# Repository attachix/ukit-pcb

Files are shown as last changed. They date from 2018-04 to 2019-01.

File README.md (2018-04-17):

## About
This repository contains the files needed to view, modify and manufacture the Printed Circuit Boards(PCB) for the [U:Kit sensor kit](https://github.com/attachix/ukit) project.

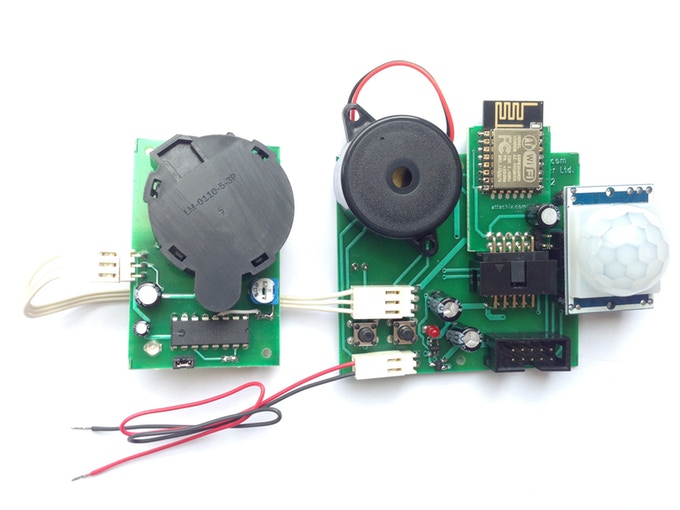
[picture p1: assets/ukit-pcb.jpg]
UKit PCBs
.

## PCBs
U:Kit consists currently of 3 PCBS
* [esp-board/](esp-board/) - ESP8266 PCB.
* [base-board/](base-board/) - the main board in the kit
* [smoke-board/](smoke-board) - the board that operates with the smoke sensor

## Hardware Overview
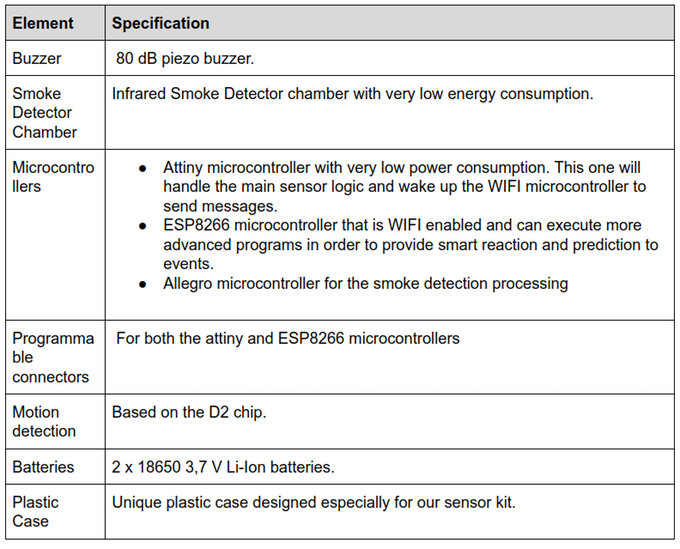
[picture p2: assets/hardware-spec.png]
Technical specification
.

## Required Software
For viewing and modifying the PCBs you will need [KiCad](http://kicad-pcb.org/) version 4.0.5 or newer.
In Ubuntu 16.04 you can install it by typing `sudo apt install kicad`.

### Optional Software
If you want to be able to see better the differences between versions you will need
* gerbv - for differences in Gerber files
* [ImageMagick](https://www.imagemagick.org) - for differences in image files
* diffpdf - for differences in PDF files
* eeplot - for differences in Schema files.

## Copyright
Copyright (c) 2016-2018, Slavey Karadzhov <slav@attachix.com>. All rights reserved.

## Authors
* Cviatko Delchev <cviatko@attachix.com> - Our hard-core hardware guru
* Slavey Karadzhov <slav@attachix.com>
* .. Contributors - See https://github.com/attachix/ukit-pcb/graphs/contributors

## License
All files in this repository are licensed under Creative Commons Non-Commercial-Share Alike 3.0 License . See the [LICENSE](LICENSE) file details. Basically it means that

### You are free to
* Share — copy and redistribute the material in any medium or format
* Adapt — remix, transform, and build upon the material

The licensor cannot revoke these freedoms as long as you follow the license terms.

### Under the following terms:
* Attribution — You must give appropriate credit, provide a link to the license, and indicate if changes were made. You may do so in any reasonable manner, but not in any way that suggests the licensor endorses you or your use.

* NonCommercial — You may not use the material for commercial purposes.

No additional restrictions — You may not apply legal terms or technological measures that legally restrict others from doing anything the license permits.

Credit can be attributed through a link to the creator website: https://attachix.com

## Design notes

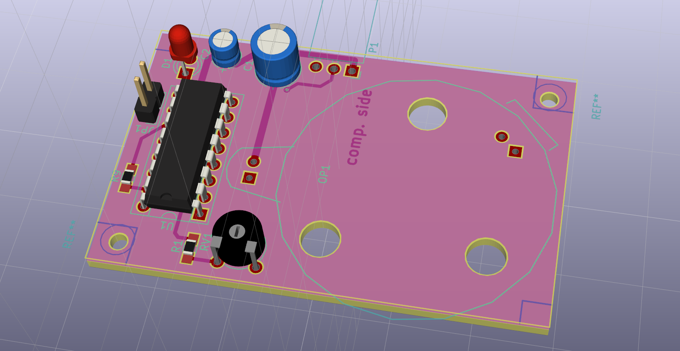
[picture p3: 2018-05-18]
smoke-board/model/CC_SM_mod_01.png

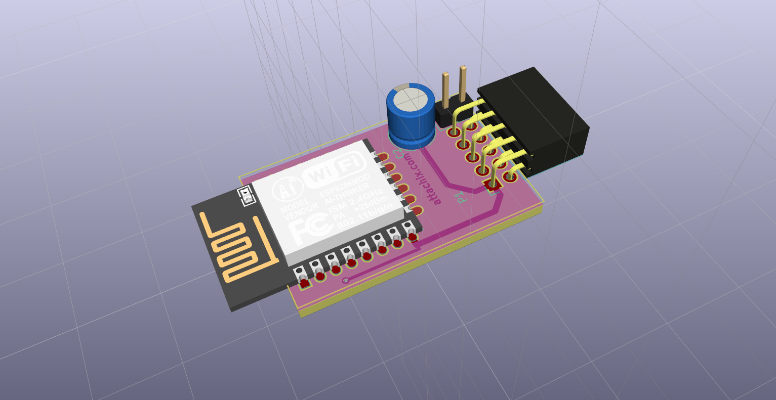
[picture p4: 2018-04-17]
esp-board/model/CC_ESP_mod_02.png

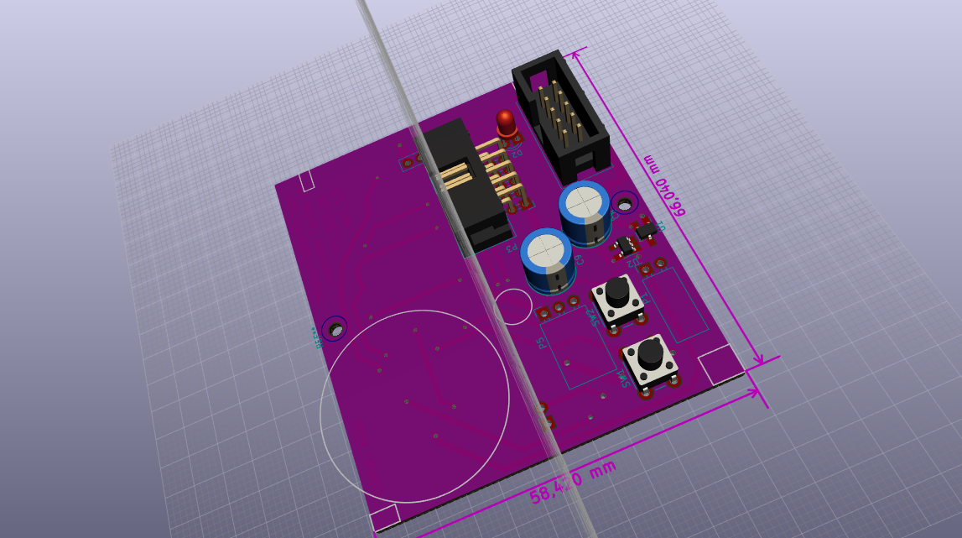
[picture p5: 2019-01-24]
base-board/model/CC_SM_mod_01.png

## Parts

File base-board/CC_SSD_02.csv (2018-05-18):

Reference | Value | Footprint | Datasheet | MF | MP | Specification | Quantity
IC1 | ATTINY1634-SU | CC_Footprint:SOIC-20W_7.5x12.8mm_Pitch1.27mm |  | Atmel | ATTINY1634-SU | https://www.verical.com/pd/atmel-microcontroller-ATTINY1634-SU-729132
P2 | BH10S | CC_Footprint:IDC_Header_Straight_10pins
P3 | BH10R | CC_Footprint:BH10R
P5 | WF3R | CC_Footprint:WF3R
P4 | PN1x3 | CC_Footprint:PN1x3
P6 | WF2R | CC_Footprint:WF2R |  | HITPOINT | PT-3110PQ | https://store.comet.bg/download-file.php?id=1015
P1 | WF2R | CC_Footprint:WF2R
U1 | MCP1701AT-3302I/CB | CC_Footprint:SOT-23_Handsoldering | MCP1701AT Series 250 mA 3.3 V LDO Positive Voltage Regulator - SOT-23 | Good | SOT-23 Microchip | Microchip | 0.65 USD | MCP1701AT-3302I/CB
U2 | MCP1802T-3302I/OT | CC_Footprint:SOT-23-5_HandSoldering | MCP1802T-3302I/OT
Q2 | DTC144TKA | CC_Footprint:SOT-23_Handsoldering
Q1 | DTC144TKA | CC_Footprint:SOT-23_Handsoldering
D2 | L-934LSRD | CC_Footprint:LED_D3.0mm
D1 | 1N5819 | CC_Footprint:D_SMA_Handsoldering
C8 | 220uF/10V | CC_Footprint:CP_Radial_D8.0mm_P2.50mm
C9 | 470uF/10V | CC_Footprint:CP_Radial_D8.0mm_P2.50mm
C4,C1,C3,C5 | 1uF | CC_Footprint:C_0805_HandSoldering
C6,C7,C11,C10,C2 | 100n | CC_Footprint:C_0805_HandSoldering
R1 | 1.8M | CC_Footprint:R_0805_HandSoldering
R2 | 200K | CC_Footprint:R_0805_HandSoldering
R11, R12 | 100k | CC_Footprint:R_0805_HandSoldering
R9, R10 | 0 | CC_Footprint:R_0805_HandSoldering
R8 | 10k | CC_Footprint:R_0805_HandSoldering
R14 | 330 | CC_Footprint:R_0805_HandSoldering
R5, R4, R3, R7, R6, R13 | 220 | CC_Footprint:R_0805_HandSoldering
SW2 | TS-06E | CC_Footprint:SW_PUSH_6mm
SW1 | TS-06E | CC_Footprint:SW_PUSH_6mm

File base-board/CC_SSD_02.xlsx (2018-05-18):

 |  |  |  |  |  |  | Board Qty: | 1
 |  |  |  |  |  |  | Total Cost: | $3.15 |  |  |  | $0.00 |  |  |  |  |  | $5.97 |  |  |  |  |  | $3.70 |  |  |  |  |  | $4.70 |  |  |  |  |  | $3.78
 |  |  |  |  |  |  | Unit Cost: | $3.15
Global Part Info |  |  |  |  |  |  |  |  | Digi-Key |  |  |  |  |  | Farnell |  |  |  |  |  | Mouser |  |  |  |  |  | Newark |  |  |  |  |  | Rs Components
Refs | Value | Desc | Footprint | Manf | Manf# | Qty | Unit$ | Ext$ | Avail | Purch | Unit$ | Ext$ | Cat# | Doc | Avail | Purch | Unit$ | Ext$ | Cat# | Doc | Avail | Purch | Unit$ | Ext$ | Cat# | Doc | Avail | Purch | Unit$ | Ext$ | Cat# | Doc | Avail | Purch | Unit$ | Ext$ | Cat# | Doc
C1,C3-C5 | 1uF |  | CC_Footprint:C_0805_HandSoldering |  |  | 4 | $0.00 | $0.00
P4 | PN1x3 |  | CC_Footprint:PN1x3 |  |  | 1 | $0.00 | $0.00
D2 | L-934LSRD |  | CC_Footprint:LED_D3.0mm |  | L-934LSRD | 1 | $0.11 | $0.11 |  |  |  |  |  |  | 4074 |  | $1.80 | $1.80 | 1142514 | Link (http://it.farnell.com/webapp/wcs/stores/servlet/Search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) |  |  |  |  | Not Assigned | Link (http://www.mouser.com/Search/../ProductDetail/Kingbright/L-934LSRD/) | 4074 |  | $0.11 | $0.11 | 26M0076 | Link (http://www.newark.com/webapp/wcs/stores/servlet/Search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)
C8 | 220uF/10V |  | CC_Footprint:CP_Radial_D8.0mm_P2.50mm |  |  | 1 | $0.00 | $0.00
R11,R12 | 100k |  | CC_Footprint:R_0805_HandSoldering |  |  | 2 | $0.00 | $0.00
R14 | 330 |  | CC_Footprint:R_0805_HandSoldering |  |  | 1 | $0.00 | $0.00
Q2 | DTC144TKA |  | CC_Footprint:SOT-23_Handsoldering | ROHM | DTC144T | 1 | $0.06 | $0.06 |  |  |  |  |  |  |  |  |  |  |  |  | 5235 |  | $0.34 | $0.34 | 755-DTC144TETL | Link (http://www.mouser.com/Search/../ProductDetail/ROHM-Semiconductor/DTC144TETL/) | 20 |  | $0.06 | $0.06 | 89Y7187 | Link (http://www.newark.com/webapp/wcs/stores/servlet/Search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) | 315 |  | $0.08 | $0.08 | 246-1738 | Link (http://it.rs-online.com/web/c/?searchTerm=DTC144T%20ROHM)
Q1 | DTC144TKA |  | CC_Footprint:SOT-23_Handsoldering | ROHM | DTC144TKA | 1 | $0.19 | $0.19 |  |  |  |  |  |  |  |  |  |  | 1680285 | Link (http://it.farnell.com/webapp/wcs/stores/servlet/Search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) | 2495 |  | $0.19 | $0.19 | 755-DTC144TKAT146 | Link (http://www.mouser.com/Search/Refine.aspx?Keyword=DTC144TKA%20ROHM)
IC1 | ATTINY1634-SU |  | CC_Footprint:SOIC-20W_7.5x12.8mm_Pitch1.27mm |  | ATTINY1634-SU | 1 | $1.54 | $1.54 |  |  |  |  |  |  | 385 |  | $2.91 | $2.91 | 2443186 | Link (http://it.farnell.com/atmel/attiny1634-su/ci-mcu-8bit/dp/2443186) | 212 |  | $1.54 | $1.54 | 556-ATTINY1634-SU | Link (http://www.mouser.com/Search/../ProductDetail/Microchip-Technology-Atmel/ATTINY1634-SU/) | 762 |  | $2.68 | $2.68 | 24W8419 | Link (http://www.newark.com/webapp/wcs/stores/servlet/Search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) | 5 |  | $2.36 | $2.36 | 814-9194 | Link (http://it.rs-online.com/web/c/?searchTerm=ATTINY1634-SU%20)
P5 | WF3R |  | CC_Footprint:WF3R |  |  | 1 | $0.00 | $0.00
P1,P6 | WF2R |  | CC_Footprint:WF2R |  |  | 2 | $0.00 | $0.00
SW1,SW2 | TS-06E |  | CC_Footprint:SW_PUSH_6mm |  |  | 2 | $0.00 | $0.00
C2,C6,C7,C10,C11 | 100n |  | CC_Footprint:C_0805_HandSoldering |  |  | 5 | $0.00 | $0.00
R3-R7,R13 | 220 |  | CC_Footprint:R_0805_HandSoldering |  |  | 6 | $0.00 | $0.00
D1 | 1N5819 |  | CC_Footprint:D_SMA_Handsoldering |  |  | 1 | $0.00 | $0.00
R2 | 200K |  | CC_Footprint:R_0805_HandSoldering |  |  | 1 | $0.00 | $0.00
U1 | MCP1701AT-3302I/CB |  | CC_Footprint:SOT-23_Handsoldering |  | MCP1701AT-3302I/CB | 1 | $0.82 | $0.82 |  |  |  |  |  |  | 3124 |  | $0.82 | $0.82 | 1605554 | Link (http://it.farnell.com/microchip/mcp1701at-3302i-cb/ic-ldo-reg-250ma-3-3v-sot-23a/dp/1605554) | 3580 |  | $1.05 | $1.05 | 579-MCP1701AT3302ICB | Link (http://www.mouser.com/Search/Refine.aspx?Keyword=MCP1701AT-3302I%2FCB%20) | 2780 |  | $1.32 | $1.32 | 11N7985 | Link (http://www.newark.com/webapp/wcs/stores/servlet/Search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) |  |  | $0.82 | $0.82 | 669-4869 | Link (http://it.rs-online.com/web/p/regolatori-di-tensione-low-dropout/6694869/)
R9,R10 | 0 |  | CC_Footprint:R_0805_HandSoldering |  |  | 2 | $0.00 | $0.00
P2 | BH10S |  | CC_Footprint:IDC_Header_Straight_10pins |  |  | 1 | $0.00 | $0.00
P3 | BH10R |  | CC_Footprint:BH10R |  |  | 1 | $0.00 | $0.00
R8 | 10k |  | CC_Footprint:R_0805_HandSoldering |  |  | 1 | $0.00 | $0.00
R1 | 1.8M |  | CC_Footprint:R_0805_HandSoldering |  |  | 1 | $0.00 | $0.00
C9 | 470uF/10V |  | CC_Footprint:CP_Radial_D8.0mm_P2.50mm |  |  | 1 | $0.00 | $0.00
U2 | MCP1802T-3302I/OT |  | CC_Footprint:SOT-23-5_HandSoldering |  | MCP1802T-3302I/OT | 1 | $0.43 | $0.43 |  |  |  |  |  |  |  |  | $0.43 | $0.43 | 2412223 | Link (http://it.farnell.com/webapp/wcs/stores/servlet/Search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) | 14080 |  | $0.58 | $0.58 | 579-MCP1802T-3302IOT | Link (http://www.mouser.com/Search/Refine.aspx?Keyword=MCP1802T-3302I%2FOT%20) | 5383 |  | $0.53 | $0.53 | 54M4838 | Link (http://www.newark.com/microchip/mcp1802t-3302i-ot/ldo-voltage-regulator-3-3v-0-3a/dp/54M4838) | 10 |  | $0.53 | $0.53 | 669-4954 | Link (http://it.rs-online.com/web/p/regolatori-di-tensione-low-dropout/6694954/)

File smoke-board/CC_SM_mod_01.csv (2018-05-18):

Reference | Value | Footprint | Datasheet | MP | Specification
OP1 | SmCh | CC_SM_mod_footprint:SmCh_LS-512-2 |  | LS-510-2
U1 | A5366 | Housings_DIP:DIP-16_W7.62mm_Socket |  | A5366CA-T
Q1 | BC847 | TO_SOT_Packages_SMD:SOT-23_Handsoldering
P1 | CONN_01X03 | CC_Footprint:WF3R
RV1 | 5K | Potentiometers:Potentiometer_Trimmer_Piher_PT-6v_Horizontal
R5 | 8K2 | Resistors_SMD:R_0805_HandSoldering
R1 | 10K | Resistors_SMD:R_0805_HandSoldering
R6 | 560R | Resistors_SMD:R_0805_HandSoldering
R2 | 200K | Resistors_SMD:R_0805_HandSoldering
R3 | 1K | Resistors_SMD:R_0805_HandSoldering
R4 | 10R | Resistors_SMD:R_0805_HandSoldering
R7 | 220R | Resistors_SMD:R_0805_HandSoldering
R9 | 10K | Resistors_SMD:R_0805_HandSoldering
R12 | 10M | Resistors_SMD:R_0805_HandSoldering
R8 | 100K | Resistors_SMD:R_0805_HandSoldering
R11 | 100K | Resistors_SMD:R_0805_HandSoldering
C4 | 47n | Capacitors_SMD:C_0805_HandSoldering
C3 | 4n7 | Capacitors_SMD:C_0805_HandSoldering
C5 | 1n5 | Capacitors_SMD:C_0805_HandSoldering
C1 | 100uF | Capacitors_THT:CP_Radial_D6.3mm_P2.50mm
C2 | 22uF | Capacitors_THT:CP_Radial_D4.0mm_P2.00mm
R10 | 1K | Resistors_SMD:R_0805_HandSoldering
JP1 | Jumper_NO | Pin_Headers:Pin_Header_Straight_1x02_Pitch2.54mm
D1 | LED | CC_Footprint:LED_D3.0mm

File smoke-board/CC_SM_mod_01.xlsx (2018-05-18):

 |  |  |  |  |  |  | Board Qty: | 1
 |  |  |  |  |  |  | Total Cost: | $1813.35 |  |  |  | $0.00 |  |  |  |  |  | $0.03 |  |  |  |  |  | $1813.39 |  |  |  |  |  | $135.80 |  |  |  |  |  | $14.06
 |  |  |  |  |  |  | Unit Cost: | $1813.35
Global Part Info |  |  |  |  |  |  |  |  | Digi-Key |  |  |  |  |  | Farnell |  |  |  |  |  | Mouser |  |  |  |  |  | Newark |  |  |  |  |  | Rs Components
Refs | Value | Desc | Footprint | Manf | Manf# | Qty | Unit$ | Ext$ | Avail | Purch | Unit$ | Ext$ | Cat# | Doc | Avail | Purch | Unit$ | Ext$ | Cat# | Doc | Avail | Purch | Unit$ | Ext$ | Cat# | Doc | Avail | Purch | Unit$ | Ext$ | Cat# | Doc | Avail | Purch | Unit$ | Ext$ | Cat# | Doc
C1 | 100uF |  | Capacitors_THT:CP_Radial_D6.3mm_P2.50mm |  |  | 1 | $0.00 | $0.00
R4 | 10R |  | Resistors_SMD:R_0805_HandSoldering |  |  | 1 | $0.00 | $0.00
R3,R10 | 1K |  | Resistors_SMD:R_0805_HandSoldering | Ohmite | AS08J1001ET | 2 | $0.06 | $0.12 |  |  |  |  |  |  |  |  |  |  |  |  | 28347 |  | $0.06 | $0.12 | 588-AS08J1001ET | Link (http://www.mouser.com/Search/Refine.aspx?Keyword=AS08J1001ET%20Ohmite) |  |  | $33.90 | $67.80 | 74Y6604 | Link (http://www.newark.com/webapp/wcs/stores/servlet/Search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)
C3 | 4n7 |  | Capacitors_SMD:C_0805_HandSoldering |  |  | 1 | $0.00 | $0.00
C2 | 22uF |  | Capacitors_THT:CP_Radial_D4.0mm_P2.00mm |  |  | 1 | $0.00 | $0.00
JP1 | Jumper_NO |  | Pin_Headers:Pin_Header_Straight_1x02_Pitch2.54mm | CVILUX | CH31022V200 | 1 | $0.00 | $0.00
R8,R11 | 100K |  | Resistors_SMD:R_0805_HandSoldering | Ohmite | AS08J1003ET | 2 | $0.06 | $0.12 |  |  |  |  |  |  |  |  |  |  |  |  | 7315 |  | $0.06 | $0.12 | 588-AS08J1003ET | Link (http://www.mouser.com/Search/Refine.aspx?Keyword=AS08J1003ET%20Ohmite)
R7 | 220R |  | Resistors_SMD:R_0805_HandSoldering |  |  | 1 | $0.00 | $0.00
R6 | 560R |  | Resistors_SMD:R_0805_HandSoldering |  |  | 1 | $0.00 | $0.00
R5 | 8K2 |  | Resistors_SMD:R_0805_HandSoldering | Panasonic | ERJ-6ENF8201V | 1 | $0.02 | $0.02 |  |  |  |  |  |  | 2952 |  | $0.02 | $0.02 | 2303646 | Link (http://it.farnell.com/panasonic-electronic-components/erj6enf8201v/res-film-spesso-8k2-1-0-125w-0805/dp/2303646) |  |  | $0.10 | $0.10 | 667-ERJ-6ENF8201V | Link (http://www.mouser.com/Search/Refine.aspx?Keyword=ERJ-6ENF8201V%20) | 44924 |  | $0.10 | $0.10 | 64R5425 | Link (http://www.newark.com/panasonic-electronic-components/erj-6enf8201v/res-thick-film-8k2-1-0-125w-0805/dp/64R5425)
RV1 | 5K |  | Potentiometers:Potentiometer_Trimmer_Piher_PT-6v_Horizontal |  |  | 1 | $0.00 | $0.00
U1 | A5366 |  | Housings_DIP:DIP-16_W7.62mm_Socket | Allegro | A5366CA-T | 1 | $0.00 | $0.00
OP1 | SmCh |  | CC_SM_mod_footprint:SmCh_LS-512-2 | LongSin | LS-510-2 | 1 | $1812.75 | $1812.75 |  |  |  |  |  |  |  |  |  |  |  |  |  |  | $1812.75 | $1812.75 | 842-PNF672/LC51024MX | Link (http://www.mouser.com/Search/Refine.aspx?Keyword=LS-510-2%20)
C5 | 1n5 |  | Capacitors_SMD:C_0805_HandSoldering |  |  | 1 | $0.00 | $0.00
R2 | 200K |  | Resistors_SMD:R_0805_HandSoldering | Panasonic | ERJ-6GEYJ204V | 1 | $0.01 | $0.01 |  |  |  |  |  |  | 67300 |  | $0.01 | $0.01 | 2057733 | Link (http://it.farnell.com/panasonic-electronic-components/erj6geyj204v/res-film-spesso-200k-5-0-125w/dp/2057733) | 68727 |  | $0.10 | $0.10 | 667-ERJ-6GEYJ204V | Link (http://www.mouser.com/Search/Refine.aspx?Keyword=ERJ-6GEYJ204V%20) | 46275 |  | $0.10 | $0.10 | 65T8800 | Link (http://www.newark.com/panasonic-electronic-components/erj-6geyj204v/res-thick-film-200k-5-0-125w-0805/dp/65T8800) | 1 |  | $13.93 | $13.93 | 732-6592 | Link (http://it.rs-online.com/web/c/?searchTerm=ERJ-6GEYJ204V%20)
P1 | CONN_01X03 |  | CC_Footprint:WF3R | CVILUX | CI3103P1H00 | 1 | $0.00 | $0.00
R1,R9 | 10K |  | Resistors_SMD:R_0805_HandSoldering | Ohmite | AS08J1002ET | 2 | $0.06 | $0.12 |  |  |  |  |  |  |  |  |  |  |  |  | 8493 |  | $0.06 | $0.12 | 588-AS08J1002ET | Link (http://www.mouser.com/Search/Refine.aspx?Keyword=AS08J1002ET%20Ohmite) |  |  | $33.90 | $67.80 | 74Y6605 | Link (http://www.newark.com/webapp/wcs/stores/servlet/Search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)
Q1 | BC847 |  | TO_SOT_Packages_SMD:SOT-23_Handsoldering | NXP_Semiconductors | BC847C | 1 | $0.14 | $0.14 |  |  |  |  |  |  |  |  |  |  |  |  |  |  |  |  | 512-BC847C | Link (http://www.mouser.com/Search/../ProductDetail/Fairchild-Semiconductor/BC847C/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) |  |  |  |  |  |  | 1100 |  | $0.14 | $0.14 | 445-2023 | Link (http://it.rs-online.com/web/p/transistor-bipolari/4452023/)
R12 | 10M |  | Resistors_SMD:R_0805_HandSoldering |  |  | 1 | $0.00 | $0.00
D1 | LED |  | CC_Footprint:LED_D3.0mm |  |  | 1 | $0.00 | $0.00
C4 | 47n |  | Capacitors_SMD:C_0805_HandSoldering | Wurth Electronics | 885012207043 | 1 | $0.08 | $0.08 |  |  |  |  |  |  |  |  |  |  |  |  |  |  | $0.08 | $0.08 | 710-885012207043 | Link (http://www.mouser.com/Search/Refine.aspx?Keyword=710-885012207043%20)

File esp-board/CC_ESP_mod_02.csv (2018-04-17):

Reference | Value | Footprint | Manufacture | Manufacture Part | Quantity | Specification
U1 | ESP-12E | ESP8266:ESP-12E | AI-Thinker | ESP-12E | 1
P1 | CONN_02X05 | Socket_Strips:Socket_Strip_Angled_2x05
R1 | 10K | Resistors_SMD:R_0805_HandSoldering | Ohmite | AS08J1002ET | 1 | http://eu.mouser.com/ProductDetail/Ohmite/AS08J1002ET/
R2 | 10K | Resistors_SMD:R_0805_HandSoldering
R3 | 220 | Resistors_SMD:R_0805_HandSoldering | Panasonic | ERJ-6GEYJ221V | 1 | http://eu.mouser.com/ProductDetail/Panasonic/ERJ-6GEYJ221V/
R4 | 220 | Resistors_SMD:R_0805_HandSoldering
R7 | 10k | Resistors_SMD:R_0805_HandSoldering
R9 | 220 | Resistors_SMD:R_0805_HandSoldering
R6 | 220 | Resistors_SMD:R_0805_HandSoldering
R8 | 220 | Resistors_SMD:R_0805_HandSoldering
R5 | 220 | Resistors_SMD:R_0805_HandSoldering
C1 | 100n | Capacitors_SMD:C_0805_HandSoldering | Yageo | AC0805KRX7R9BB104 | 1 | http://eu.mouser.com/ProductDetail/Yageo/AC0805KRX7R9BB104/
C2 | 220u | Capacitors_THT:CP_Radial_D6.3mm_P2.50mm | Panasonic | ECA-1CM221 | 1 | http://eu.mouser.com/ProductDetail/Panasonic/ECA-1CM221/
P2 | CONN_01X02 | Socket_Strips:Socket_Strip_Straight_1x02

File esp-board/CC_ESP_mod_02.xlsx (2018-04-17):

 |  |  |  |  |  |  | Board Qty: | 1
 |  |  |  |  |  |  | Total Cost: | $0.62 |  |  |  | $0.00 |  |  |  |  |  | $0.31 |  |  |  |  |  | $1.19 |  |  |  |  |  | $102.55 |  |  |  |  |  | $115.00
 |  |  |  |  |  |  | Unit Cost: | $0.62
Global Part Info |  |  |  |  |  |  |  |  | Digi-Key |  |  |  |  |  | Farnell |  |  |  |  |  | Mouser |  |  |  |  |  | Newark |  |  |  |  |  | Rs Components
Refs | Value | Desc | Footprint | Manf | Manf# | Qty | Unit$ | Ext$ | Avail | Purch | Unit$ | Ext$ | Cat# | Doc | Avail | Purch | Unit$ | Ext$ | Cat# | Doc | Avail | Purch | Unit$ | Ext$ | Cat# | Doc | Avail | Purch | Unit$ | Ext$ | Cat# | Doc | Avail | Purch | Unit$ | Ext$ | Cat# | Doc
P2 | CONN_01X02 |  | Socket_Strips:Socket_Strip_Straight_1x02 | CVILUX | CH31022V200 | 1 | $0.00 | $0.00
C2 | 220u |  | Capacitors_THT:CP_Radial_D6.3mm_P2.50mm | Panasonic | ECA-1CM221 | 1 | $0.21 | $0.21 |  |  |  |  |  |  | 1673 |  | $0.25 | $0.25 | 2282200 | Link (http://it.farnell.com/panasonic-electronic-components/eca-1cm221b/aluminum-electrolytic-capacitor/dp/2282200) | 5847 |  | $0.25 | $0.25 | 667-ECA-1CM221 | Link (http://www.mouser.com/Search/../ProductDetail/Panasonic/ECA-1CM221/) | 4065 |  | $0.25 | $0.25 | 96K9151 | Link (http://www.newark.com/panasonic-electronic-components/eca-1cm221/aluminum-electrolytic-capacitor/dp/96K9151) | 40 |  | $0.21 | $0.21 | 228-6666 | Link (http://it.rs-online.com/web/p/condensatori-elettrolitici/2286666/)
R3-R6,R8,R9 | 220 |  | Resistors_SMD:R_0805_HandSoldering | Panasonic | ERJ-6GEYJ221V | 6 | $0.01 | $0.07 |  |  |  |  |  |  | 23632 |  | $0.01 | $0.07 | 2057687 | Link (http://it.farnell.com/panasonic-electronic-components/erj6geyj221v/res-film-spesso-220r-5-0-125w/dp/2057687) | 152249 |  | $0.10 | $0.60 | 667-ERJ-6GEYJ221V | Link (http://www.mouser.com/Search/Refine.aspx?Keyword=ERJ-6GEYJ221V%20) | 2135 |  | $0.10 | $0.60 | 65T8803 | Link (http://www.newark.com/panasonic-electronic-components/erj-6geyj221v/res-thick-film-220r-5-0-125w-0805/dp/65T8803) | 44 |  | $11.83 | $70.99 | 732-6605 | Link (http://it.rs-online.com/web/c/?searchTerm=ERJ-6GEYJ221V%20)
P1 | CONN_02X05 |  | Socket_Strips:Socket_Strip_Angled_2x05 | CVILUX | CB94102H100 | 1 | $0.00 | $0.00
U1 | ESP-12E |  | ESP8266:ESP-12E | AI-Thinkerer | ESP8266-12E | 1 | $0.00 | $0.00
R1,R2,R7 | 10K |  | Resistors_SMD:R_0805_HandSoldering | Ohmite | AS08J1002ET | 3 | $0.06 | $0.18 |  |  |  |  |  |  |  |  |  |  |  |  | 8493 |  | $0.06 | $0.18 | 588-AS08J1002ET | Link (http://www.mouser.com/Search/Refine.aspx?Keyword=AS08J1002ET%20Ohmite) |  |  | $33.90 | $101.70 | 74Y6605 | Link (http://www.newark.com/webapp/wcs/stores/servlet/Search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)
C1 | 100n |  | Capacitors_SMD:C_0805_HandSoldering | Yageo | AC0805KRX7R9BB104 | 1 | $0.16 | $0.16 |  |  |  |  |  |  |  |  |  |  |  |  |  |  | $0.16 | $0.16 | 603-AC0805KR9BB104 | Link (http://www.mouser.com/Search/Refine.aspx?Keyword=AC0805KRX7R9BB104%20Yageo) |  |  |  |  |  |  | 2 |  | $43.80 | $43.80 | 669-8842 | Link (http://it.rs-online.com/web/c/?searchTerm=AC0805KRX7R9BB104%20Yageo)

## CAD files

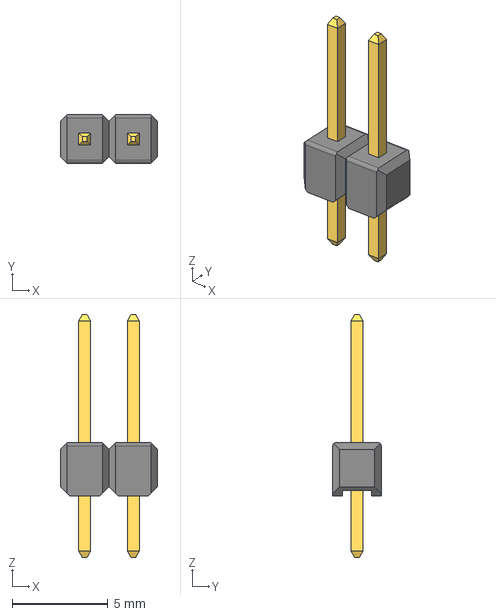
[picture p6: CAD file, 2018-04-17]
.kicad/parts/Pin Header 1x2 TH Pitch 2.54mm.stp
5.08 x 2.54 x 12.7 mm

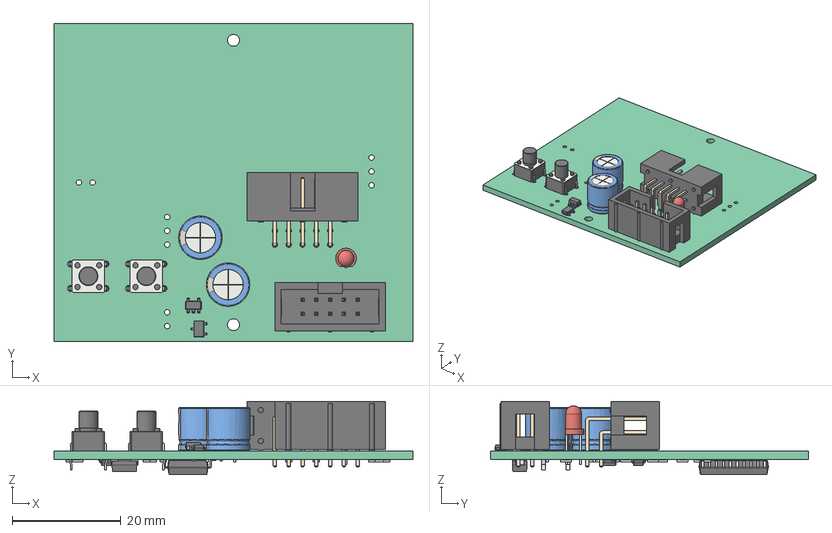
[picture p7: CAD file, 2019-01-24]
base-board/model/CC_SSD_02.step
66.0 x 58.4 x 13.5 mm
PCB_Sketch
C8_CP_Radial_D80mm_P250mm_58AA0B78
C9_CP_Radial_D80mm_P250mm_58AA0C20
D2_LED_D3.0mm_58AA0C6A
P3_IDC_Header_2x05_P254mm_Horizontal_58AA0D41
SW1_SW_PUSH_6mm_58AA0EDA
SW1_SW_PUSH_6mm_h7.3mm_58AA0EDA[2]
SW2_SW_PUSH_6mm_h7.3mm_58AA0EF8
U1_SOT_23W_58AA0F0C
U2_SOT_23_5_58AA0F20
P2_IDC_Header_2x05_P254mm_Vertical_5BACADFA
D1_D_SMA_58AA0C57
IC1_SOIC_20W_75x128mm_P127mm_58AA0C92
Q1_SOT_23W_58AA0DC8
Q2_SOT_23W_58AA0DDC
R1_R_0805_2012Metric_58AA0DEC
R2_R_0805_2012Metric_58AA0DFC
R3_R_0805_2012Metric_58AA0E0C
R4_R_0805_2012Metric_58AA0E1C
R5_R_0805_2012Metric_58AA0E2C
R6_R_0805_2012Metric_58AA0E3C
R7_R_0805_2012Metric_58AA0E4C
R8_R_0805_2012Metric_58AA0E5C
R9_R_0805_2012Metric_58AA0E6C
R10_R_0805_2012Metric_58AA0E7C
R11_R_0805_2012Metric_58AA0E8C
R12_R_0805_2012Metric_58AA0E9C
R13_R_0805_2012Metric_58AA0EAC
R14_R_0805_2012Metric_58AA0EBC

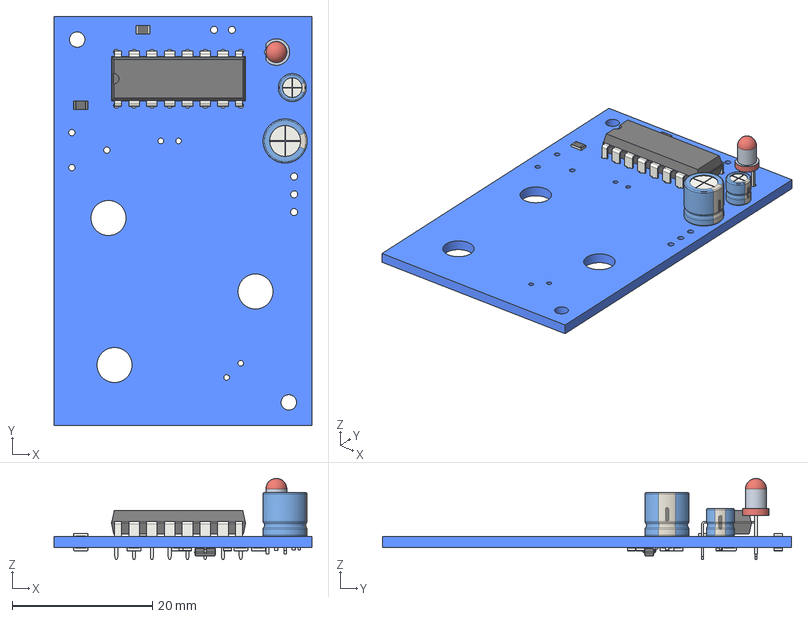
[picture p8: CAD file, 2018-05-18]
smoke-board/model/CC_SM_mod_01.step
36.8 x 58.4 x 11.6 mm
Pcb
SOT_23_
CP_Radial_D63mm_P250mm_
CP_Radial_D40mm_P200mm_
LED_D3.0mm_
R_0805_2012Metric_
R_0805_2012Metric_001
R_0805_2012Metric_002
R_0805_2012Metric_003
R_0805_2012Metric_004
R_0805_2012Metric_005
R_0805_2012Metric_006
R_0805_2012Metric_007
R_0805_2012Metric_008
R_0805_2012Metric_009
R_0805_2012Metric_010
R_0805_2012Metric_011
DIP-16_W7.62mm_

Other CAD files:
base-board/CC_SSD_02.step

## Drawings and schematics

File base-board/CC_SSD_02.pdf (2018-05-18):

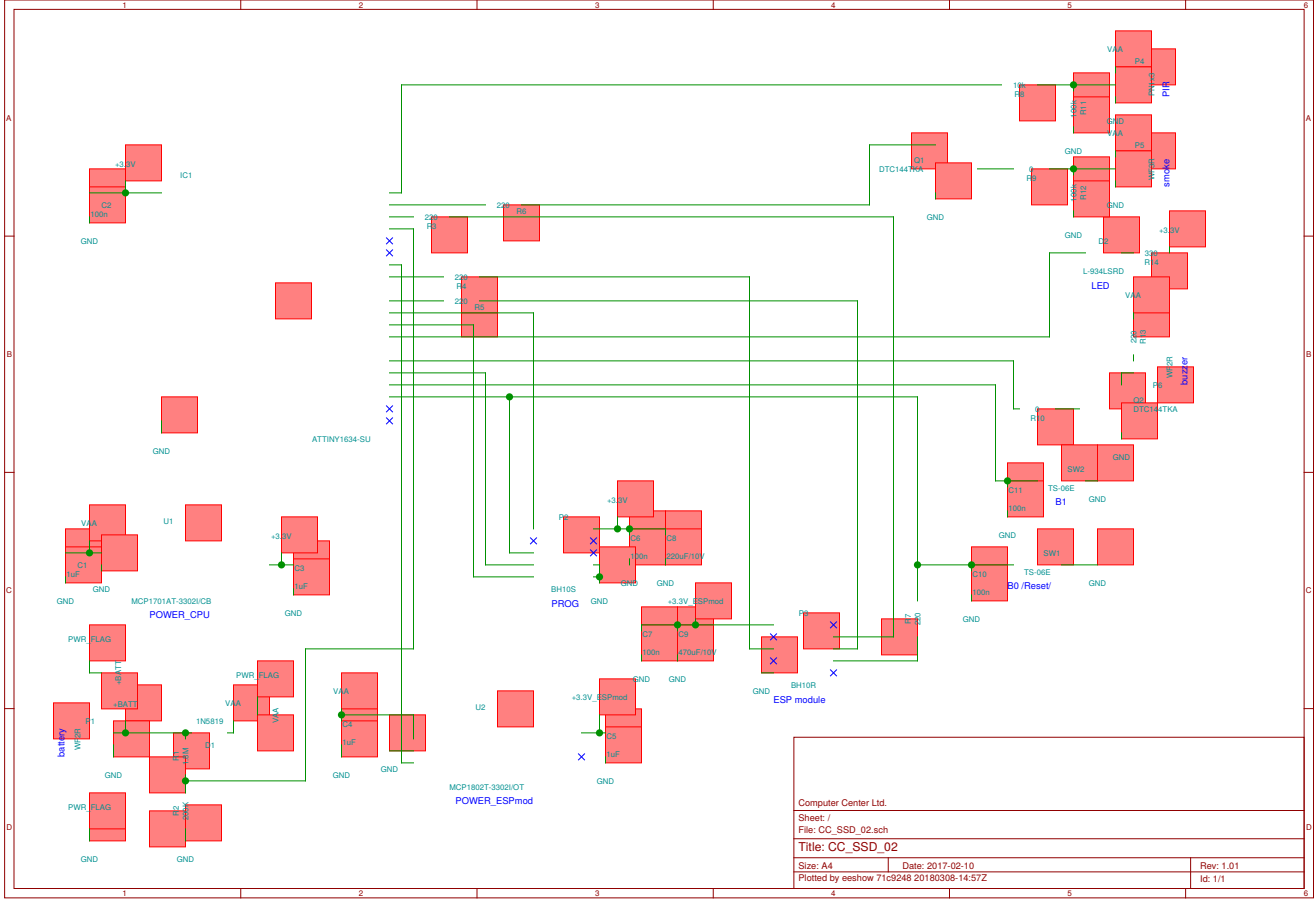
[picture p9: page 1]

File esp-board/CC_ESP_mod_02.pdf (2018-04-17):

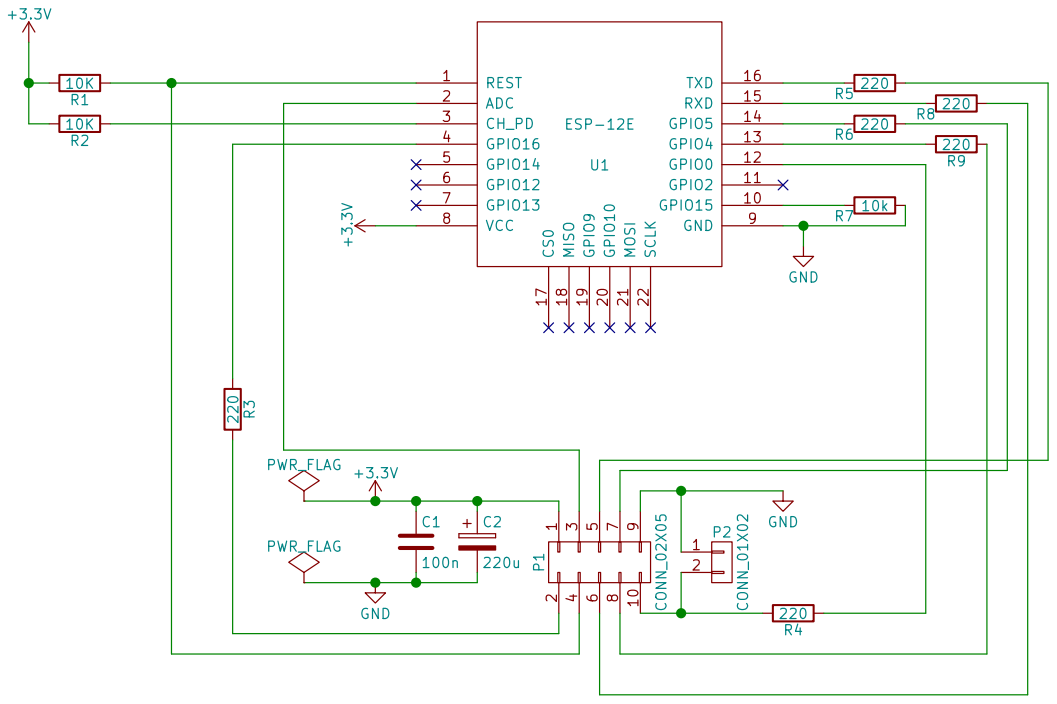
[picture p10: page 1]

File: CC_ESP_mod_02.sch Sheet: / Computer Center Ltd.

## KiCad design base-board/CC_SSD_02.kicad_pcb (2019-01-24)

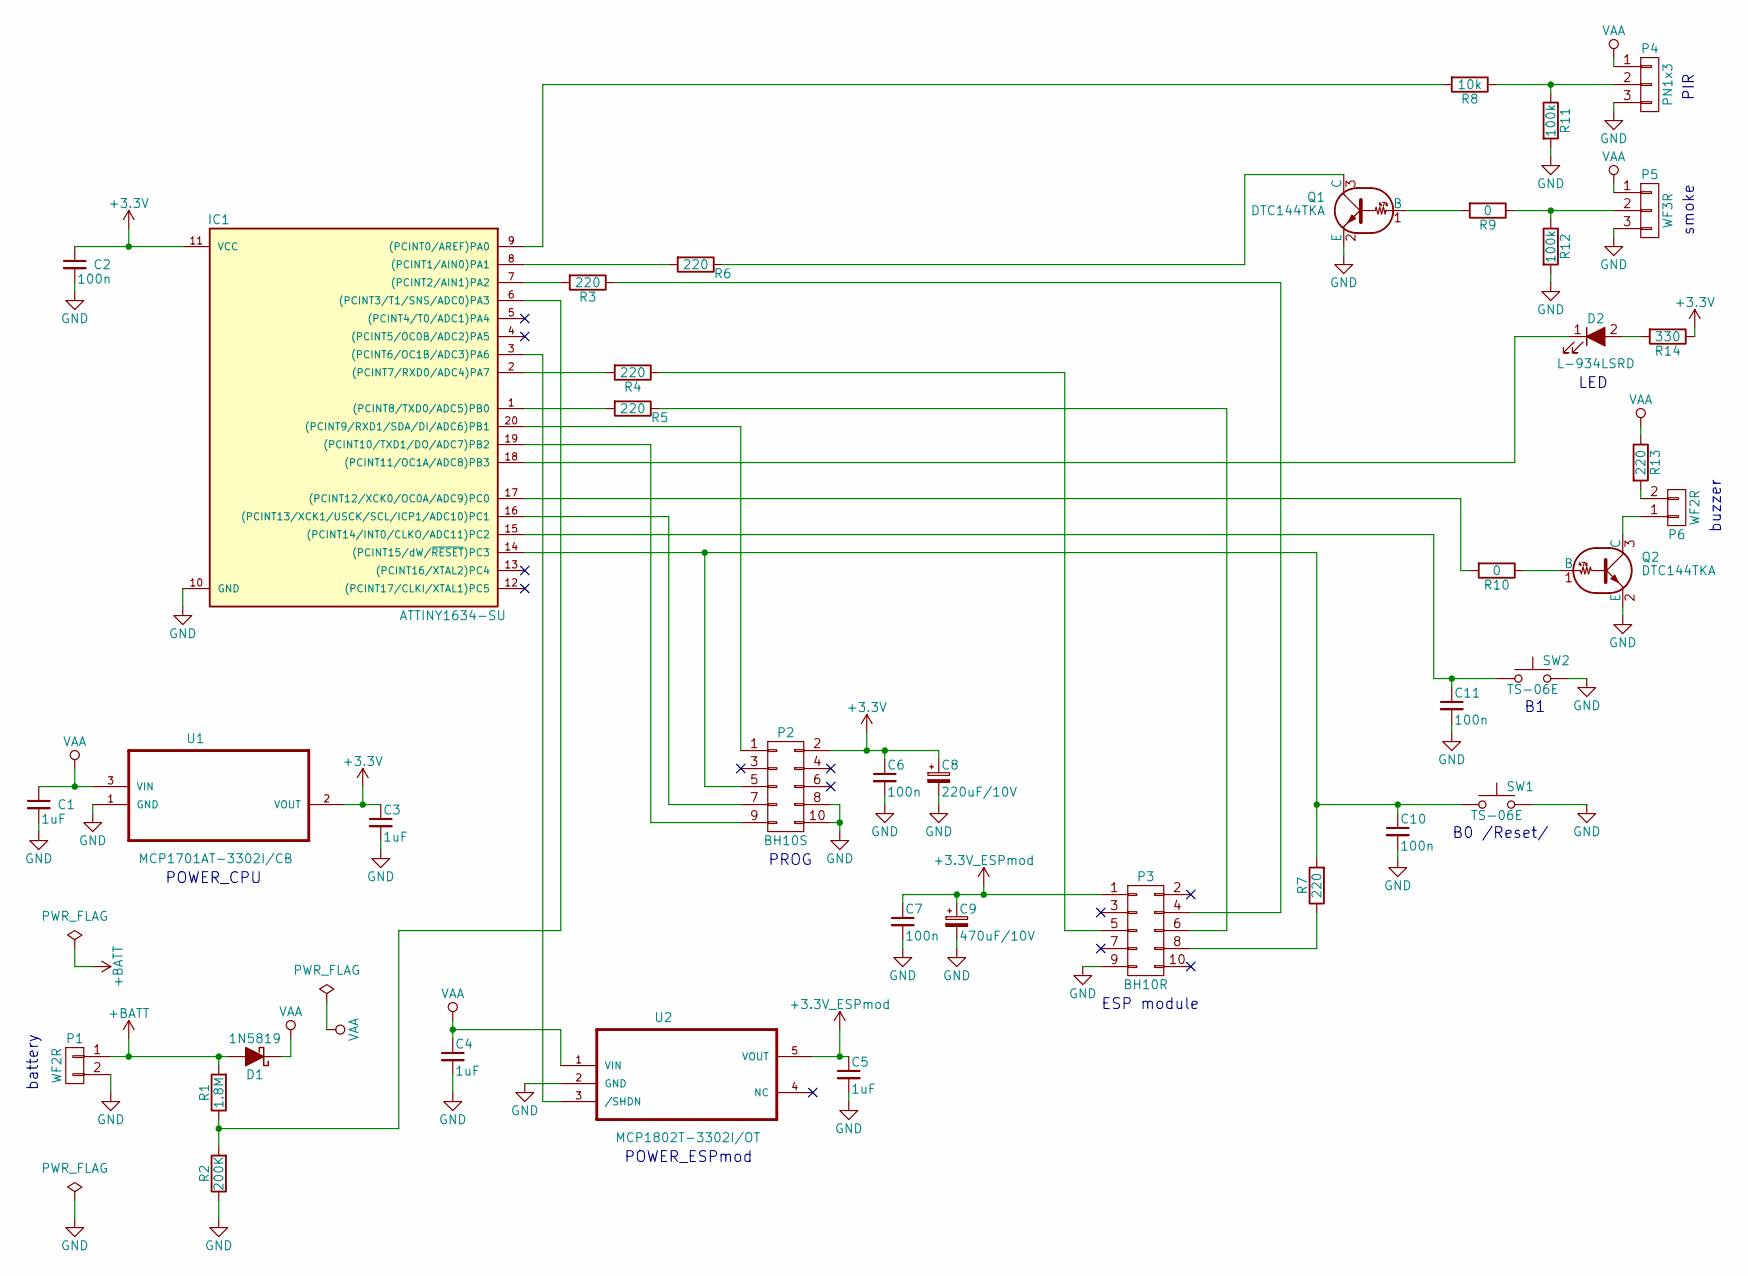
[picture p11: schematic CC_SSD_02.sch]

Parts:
C1, C3, C4, C5: 1uF; C_0805_HandSoldering
C2, C6, C7, C10, C11: 100n; C_0805_HandSoldering
C8: 220uF/10V; CP_Radial_D8.0mm_P2.50mm
C9: 470uF/10V; CP_Radial_D8.0mm_P2.50mm
D1: 1N5819; D_SMA_Handsoldering
D2: L-934LSRD; LED_D3.0mm
IC1: ATTINY1634-SU; SOIC-20W_7.5x12.8mm_Pitch1.27mm
P1, P6: WF2R
P2: BH10S; IDC_Header_Straight_10pins
P3: BH10R
P4: PN1x3
P5: WF3R
Q1, Q2: DTC144TKA; SOT-23_Handsoldering
R1: 1.8M; R_0805_HandSoldering
R2: 200K; R_0805_HandSoldering
R3, R4, R5, R6, R7, R13: 220; R_0805_HandSoldering
R8: 10k; R_0805_HandSoldering
R9, R10: 0; R_0805_HandSoldering
R11, R12: 100k; R_0805_HandSoldering
R14: 330; R_0805_HandSoldering
SW1, SW2: TS-06E; SW_PUSH_6mm
U1: MCP1701AT-3302I/CB; SOT-23_Handsoldering
U2: MCP1802T-3302I/OT; SOT-23-5_HandSoldering

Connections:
+3.3V_ESPmod: C5.1, C7.1, C9.1, P3.1, U2.5 (VOUT)
+3V3: C2.1, C3.1, C6.1, C8.1, IC1.11 (VCC), P2.2, R14.1, U1.2 (VOUT)
+BATT: D1.2 (A), P1.1, R1.2
GND: C1.2, C2.2, C3.2, C4.2, C5.2, C6.2, C7.2, C8.2, C9.2, C10.2, C11.2, IC1.10 (GND), P1.2, P2.8, P2.10, P3.9, P4.3, P5.3, Q1.2 (E), Q2.2 (E), R2.1, R11.2, R12.2, SW1.2, SW2.2, U1.1 (GND), U2.2 (GND)
unnamed: C10.1, IC1.14 ((PCINT15/dW/~RESET~)PC3), P2.5, R7.2, SW1.1
unnamed: C11.1, IC1.15 ((PCINT14/INT0/CLKO/ADC11)PC2), SW2.1
unnamed: D2.1 (K), IC1.18 ((PCINT11/OC1A/ADC8)PB3)
unnamed: D2.2 (A), R14.2
unnamed: IC1.1 ((PCINT8/TXD0/ADC5)PB0), R5.2
unnamed: IC1.2 ((PCINT7/RXD0/ADC4)PA7), R4.2
unnamed: IC1.3 ((PCINT6/OC1B/ADC3)PA6), U2.3 (/SHDN)
unnamed: IC1.6 ((PCINT3/T1/SNS/ADC0)PA3), R1.1, R2.2
unnamed: IC1.7 ((PCINT2/AIN1)PA2), R3.2
unnamed: IC1.8 ((PCINT1/AIN0)PA1), R6.2
unnamed: IC1.9 ((PCINT0/AREF)PA0), R8.2
unnamed: IC1.16 ((PCINT13/XCK1/USCK/SCL/ICP1/ADC10)PC1), P2.7
unnamed: IC1.17 ((PCINT12/XCK0/OC0A/ADC9)PC0), R10.2
unnamed: IC1.19 ((PCINT10/TXD1/DO/ADC7)PB2), P2.9
unnamed: IC1.20 ((PCINT9/RXD1/SDA/DI/ADC6)PB1), P2.1
unnamed: P3.4, R3.1
unnamed: P3.5, R4.1
unnamed: P3.6, R5.1
unnamed: P3.8, R7.1
unnamed: P4.2, R8.1, R11.1
unnamed: P5.2, R9.1, R12.1
unnamed: P6.1, Q2.3 (C)
unnamed: P6.2, R13.2
unnamed: Q1.1 (B), R9.2
unnamed: Q1.3 (C), R6.1
unnamed: Q2.1 (B), R10.1
VAA: C1.1, C4.1, D1.1 (K), P4.1, P5.1, R13.1, U1.3 (VIN), U2.1 (VIN)

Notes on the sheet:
PROG
ESP module
B0 /Reset/
buzzer
smoke
battery
PIR
LED
POWER_CPU
POWER_ESPmod

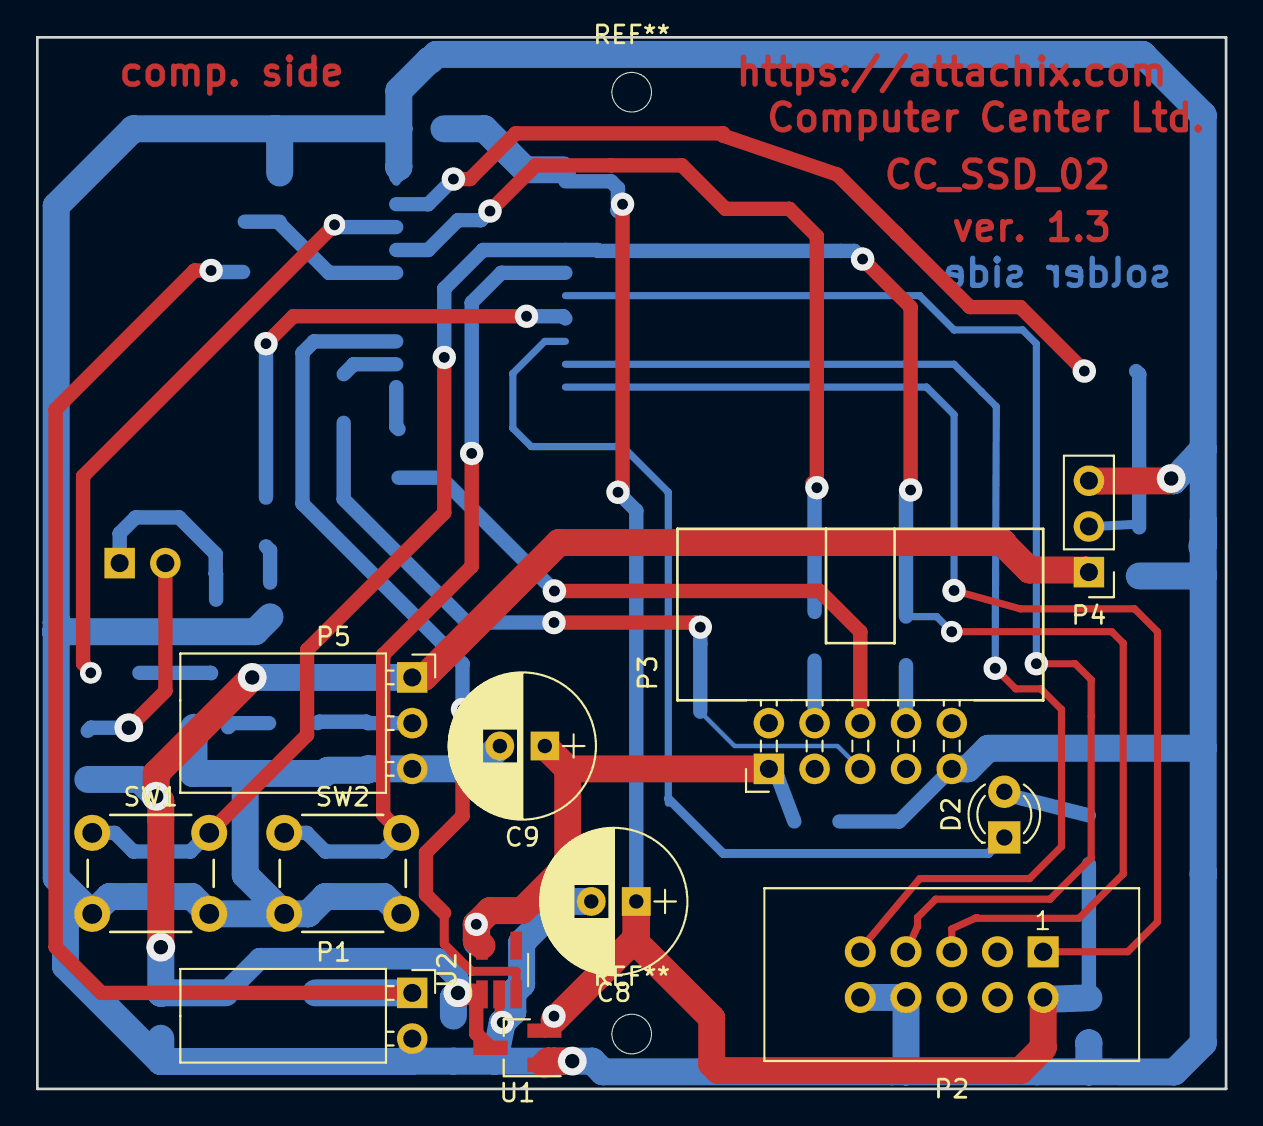
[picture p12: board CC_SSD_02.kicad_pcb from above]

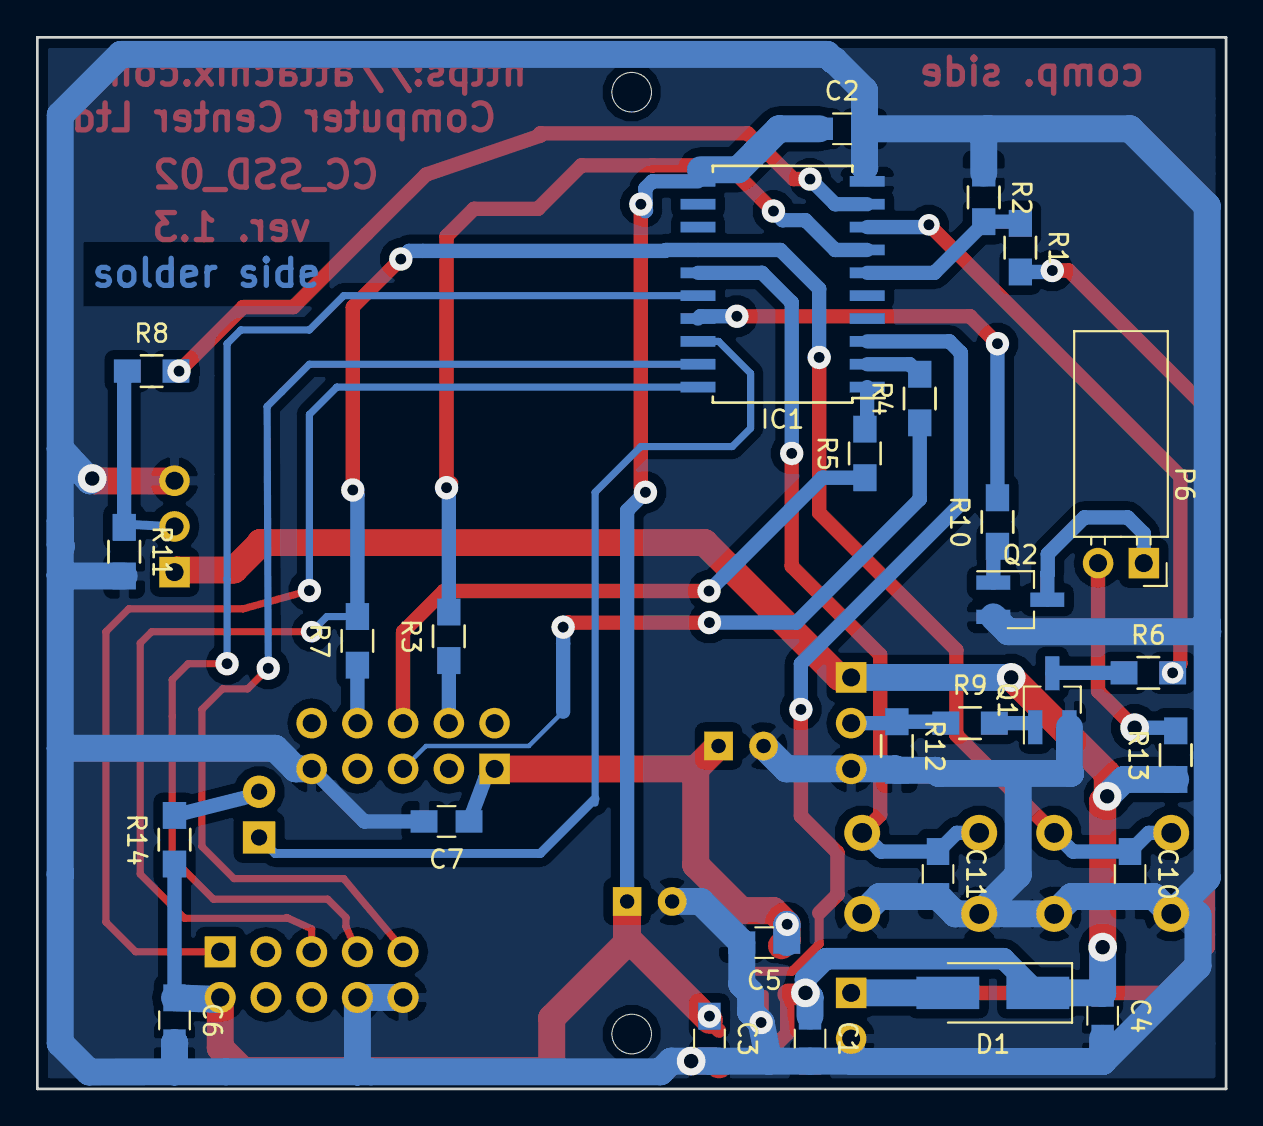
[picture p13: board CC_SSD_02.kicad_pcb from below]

Board: 2 copper layers, 66.0 x 58.4 mm, 40 parts (28 on the bottom side), 31 nets.

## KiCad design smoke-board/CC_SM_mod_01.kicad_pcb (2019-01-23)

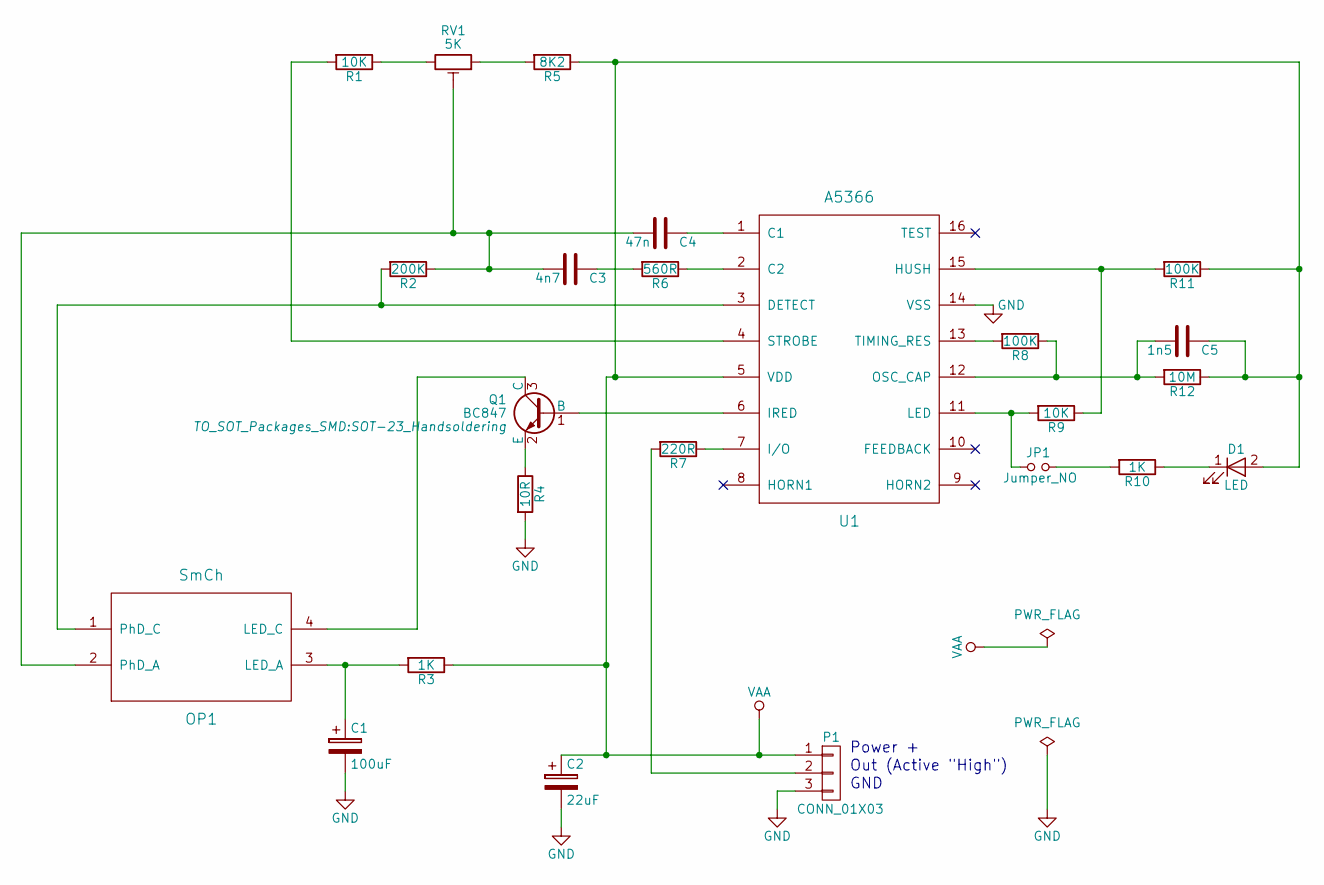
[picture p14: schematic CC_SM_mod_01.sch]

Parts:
C1: 100uF; CP_Radial_D6.3mm_P2.50mm
C2: 22uF; CP_Radial_D4.0mm_P2.00mm
C3: 4n7; C_0805_HandSoldering
C4: 47n; C_0805_HandSoldering; mouser# 710-885012207043
C5: 1n5; C_0805_HandSoldering
D1: LED; LED_D3.0mm
JP1: Jumper_NO; Pin_Header_Straight_1x02_Pitch2.54mm
OP1: SmCh; SmCh_LS-512-2
P1: CONN_01X03; WF3R
Q1: BC847; SOT-23_Handsoldering
R1, R9: 10K; R_0805_HandSoldering
R2: 200K; R_0805_HandSoldering
R3, R10: 1K; R_0805_HandSoldering
R4: 10R; R_0805_HandSoldering
R5: 8K2; R_0805_HandSoldering
R6: 560R; R_0805_HandSoldering
R7: 220R; R_0805_HandSoldering
R8, R11: 100K; R_0805_HandSoldering
R12: 10M; R_0805_HandSoldering
RV1: 5K; Potentiometer_Trimmer_Piher_PT-6v_Horizontal
U1: A5366; DIP-16_W7.62mm_Socket

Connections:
GND: C1.2, C2.2, P1.3, R4.2, U1.14 (VSS)
unnamed: C1.1, OP1.3 (LED_A), R3.2
unnamed: C3.1, R6.2
unnamed: C3.2, C4.2, OP1.2 (PhD_A), R2.1, RV1.2
unnamed: C4.1, U1.1 (C1)
unnamed: C5.2, R8.1, R12.2, U1.12 (OSC_CAP)
unnamed: D1.1 (K), R10.1
unnamed: JP1.1, R9.2, U1.11 (LED)
unnamed: JP1.2, R10.2
unnamed: OP1.1 (PhD_C), R2.2, U1.3 (DETECT)
unnamed: OP1.4 (LED_C), Q1.3 (C)
unnamed: P1.2, R7.2
unnamed: Q1.1 (B), U1.6 (IRED)
unnamed: Q1.2 (E), R4.1
unnamed: R1.1, RV1.3
unnamed: R1.2, U1.4 (STROBE)
unnamed: R5.2, RV1.1
unnamed: R6.1, U1.2 (C2)
unnamed: R7.1, U1.7 (I/O)
unnamed: R8.2, U1.13 (TIMING_RES)
unnamed: R9.1, R11.2, U1.15 (HUSH)
VAA: C2.1, C5.1, D1.2 (A), P1.1, R3.1, R5.1, R11.1, R12.1, U1.5 (VDD)

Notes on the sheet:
Power +
Out (Active "High")
GND

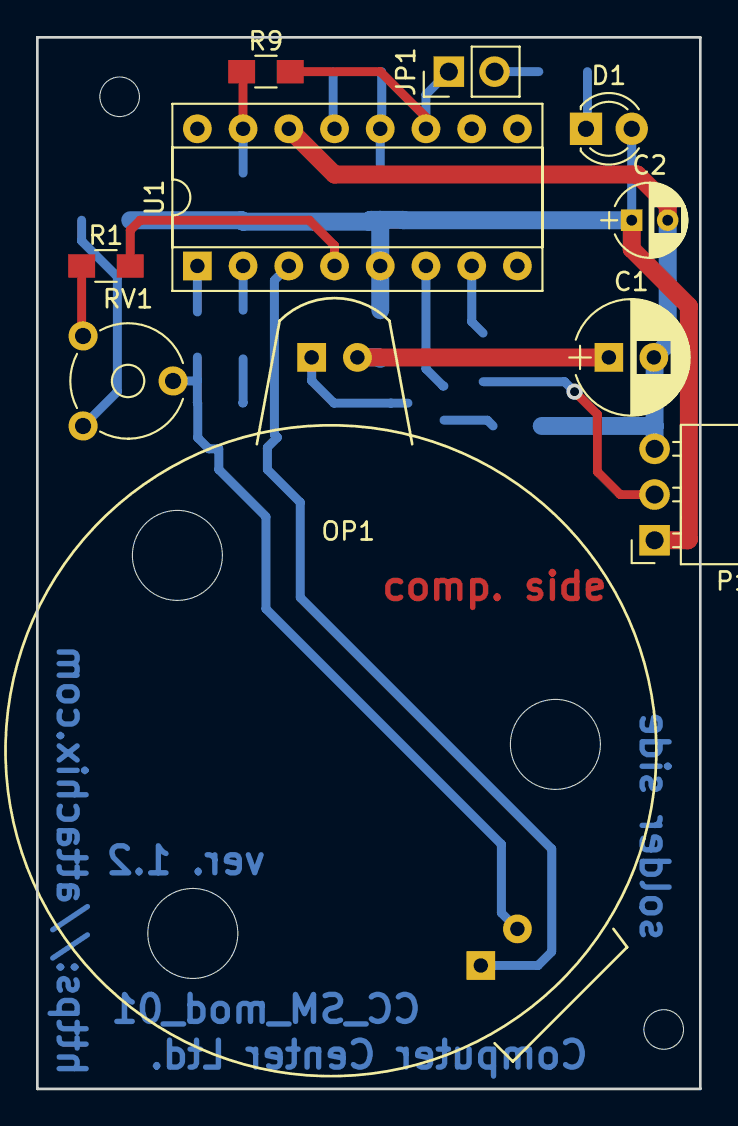
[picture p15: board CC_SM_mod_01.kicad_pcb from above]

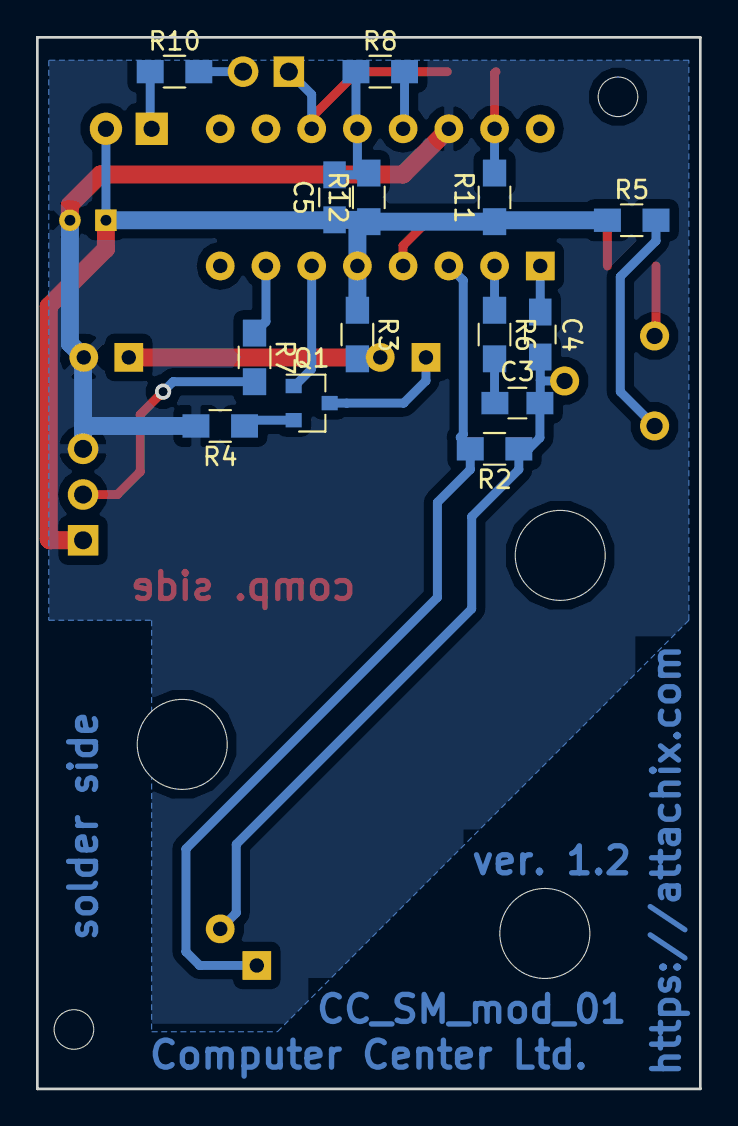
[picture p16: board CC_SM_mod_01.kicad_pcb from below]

Board: 2 copper layers, 36.8 x 58.4 mm, 24 parts (14 on the bottom side), 22 nets.

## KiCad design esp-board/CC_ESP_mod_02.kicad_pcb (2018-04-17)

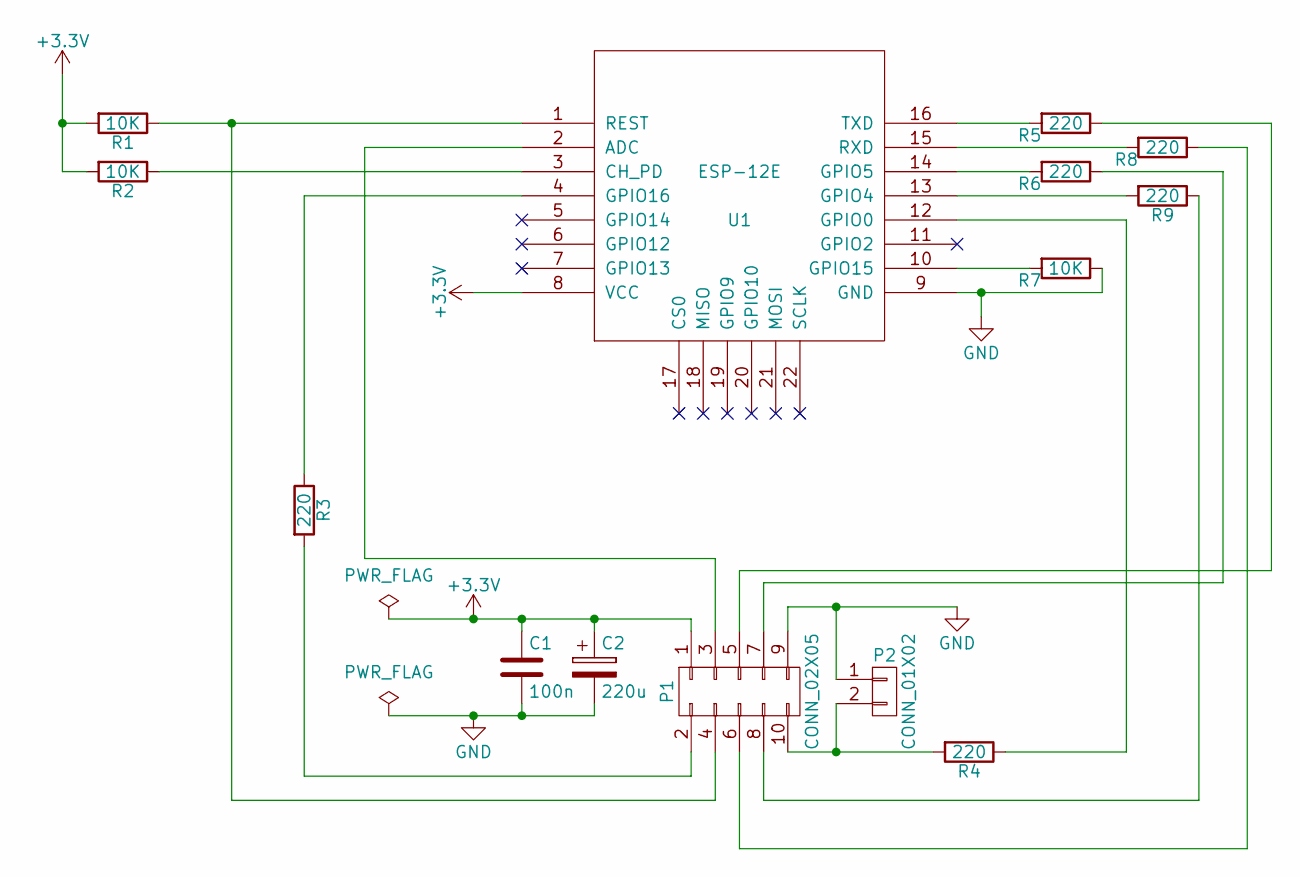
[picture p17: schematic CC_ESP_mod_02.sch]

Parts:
C1: 100n; C_0805_HandSoldering
C2: 220u; CP_Radial_D6.3mm_P2.50mm
P1: CONN_02X05; Socket_Strip_Angled_2x05
P2: CONN_01X02; Socket_Strip_Straight_1x02
R1, R2, R7: 10K; R_0805_HandSoldering
R3, R4, R5, R6, R8, R9: 220; R_0805_HandSoldering
U1: ESP-12E

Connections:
+3V3: C1.1, C2.1, P1.1, R1.2, R2.2, U1.8 (VCC)
GND: C1.2, C2.2, P1.9, P2.1, R7.1, U1.9 (GND)
unnamed: P1.2, R3.2
unnamed: P1.3, U1.2 (ADC)
unnamed: P1.4, R1.1, U1.1 (REST)
unnamed: P1.5, R5.1
unnamed: P1.6, R8.1
unnamed: P1.7, R6.1
unnamed: P1.8, R9.1
unnamed: P1.10, P2.2, R4.2
unnamed: R2.1, U1.3 (CH_PD)
unnamed: R3.1, U1.4 (GPIO16)
unnamed: R4.1, U1.12 (GPIO0)
unnamed: R5.2, U1.16 (TXD)
unnamed: R6.2, U1.14 (GPIO5)
unnamed: R7.2, U1.10 (GPIO15)
unnamed: R8.2, U1.15 (RXD)
unnamed: R9.2, U1.13 (GPIO4)

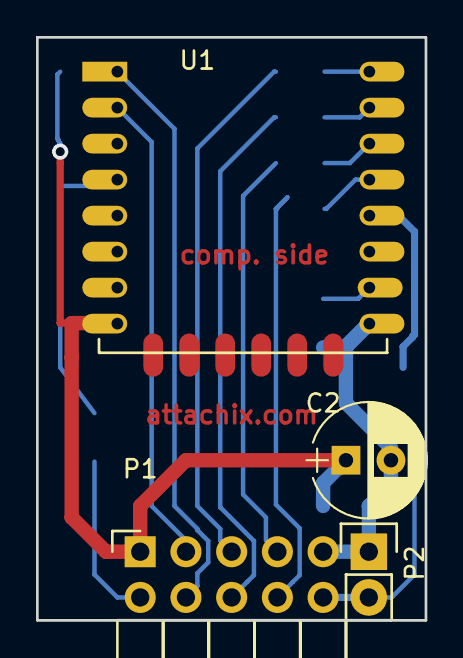
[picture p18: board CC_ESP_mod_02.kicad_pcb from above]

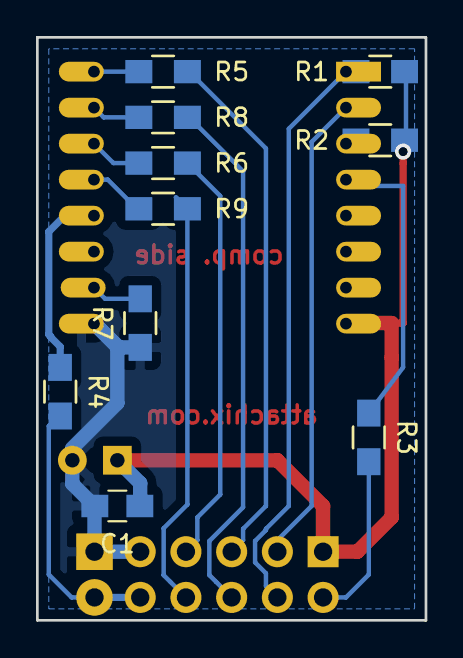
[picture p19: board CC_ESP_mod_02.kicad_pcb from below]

Board: 2 copper layers, 21.6 x 32.4 mm, 14 parts (10 on the bottom side), 18 nets.

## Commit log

2018-04-17 Initial public version of the ESP8266-board.
    [CC_ESP_mod_02.csv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]
2018-05-18 Added the base-board and the smoke-board. All PCBs needed to build the device are not present.
    [CC_SM_mod_01-B.Cu.gbr, CC_SM_mod_01-B.Mask.gbr, CC_SM_mod_01-B.SilkS.gbr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]
2018-10-01 Moved smoke detector header more to the center. Reverted header for Attiny programmer to be straight.
    [CC_SSD_02.kicad_pcb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]
2019-01-23 Slightly moved the holes so that the smoke PCB does not push the walls of the enclosure.
    [CC_SM_mod_01.kicad_pcb]
2019-01-24 Added new version of the base board with fixes for the connectors and LED moved closer to the ring.
    [CC_SSD_02.kicad_pcb, CC_SSD_02.step]
